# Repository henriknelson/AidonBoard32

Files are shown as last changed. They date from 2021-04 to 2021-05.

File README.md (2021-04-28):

# AidonBoard32
KiCad hardware project to facilitate the reading and forwarding of meter value data pushed through the P1-interface on electricity meters produced by Aidon together with a Espressifs ESP32-WROOM module on a single PCB.

3D View:
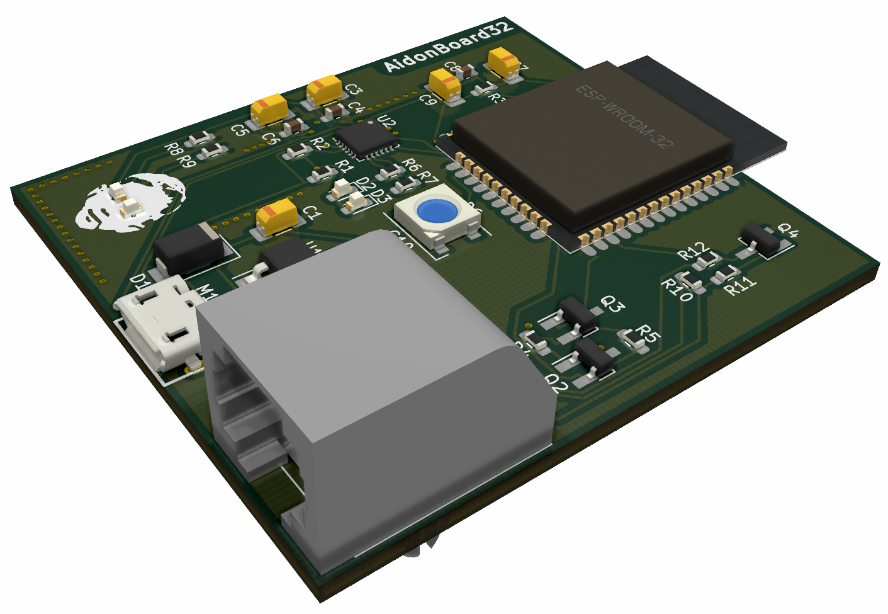
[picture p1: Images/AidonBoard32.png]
AidonBoard32 PCB 3D View


Schematic:
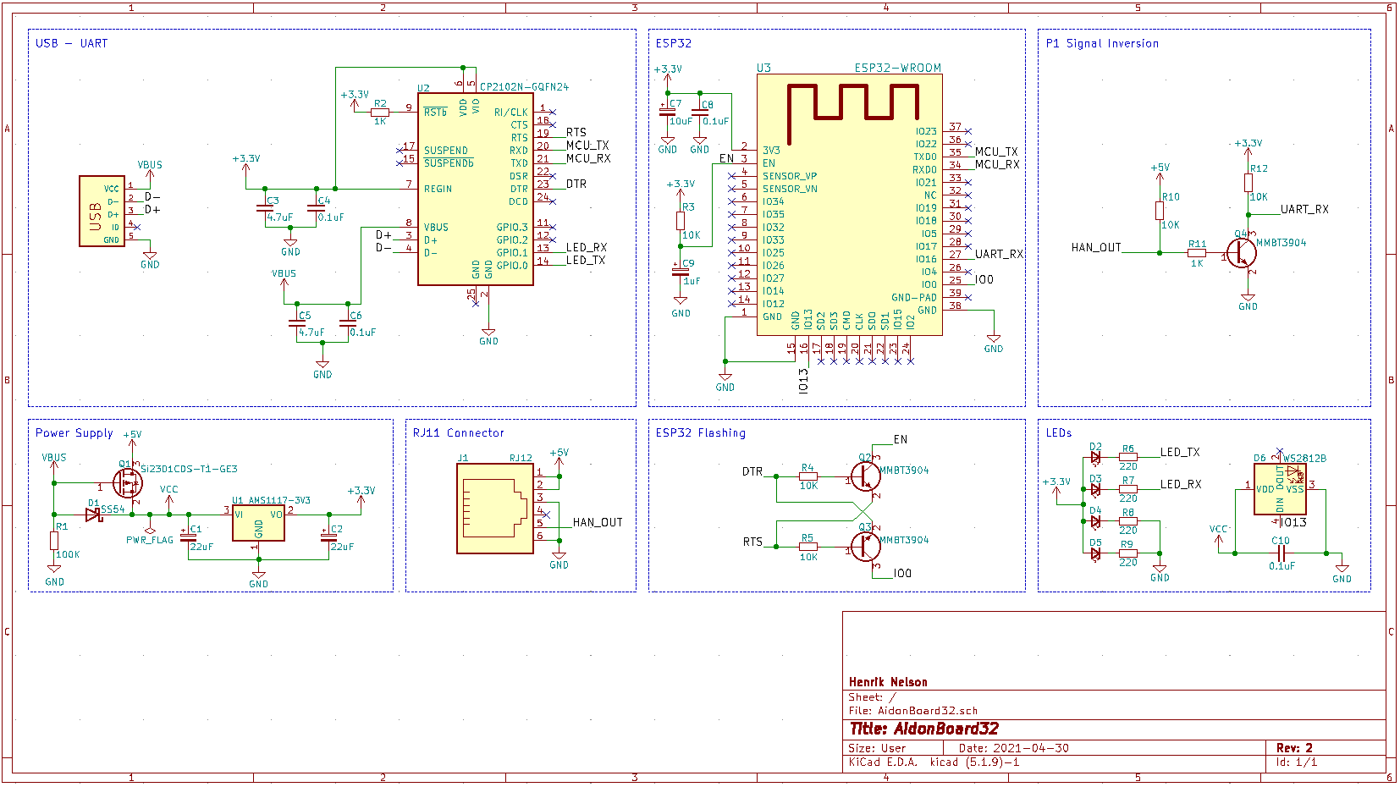
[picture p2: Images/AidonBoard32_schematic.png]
AidonBoard32 Schematic


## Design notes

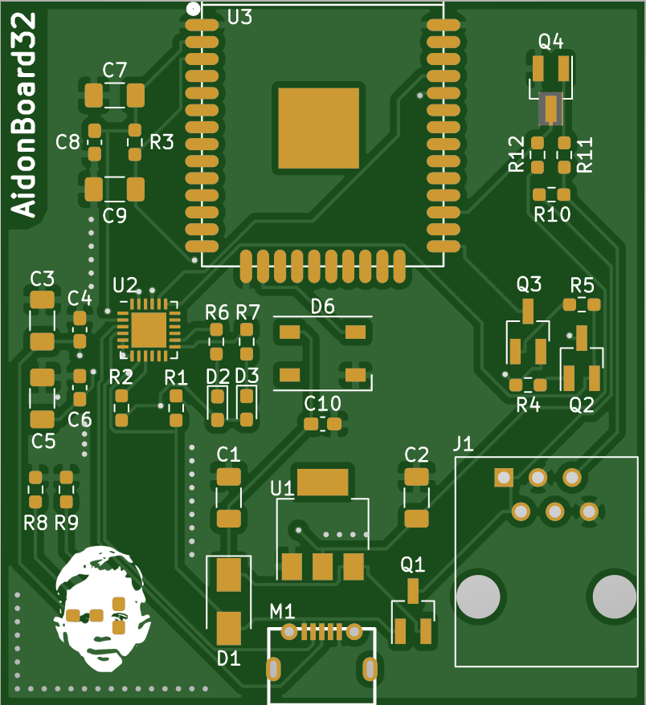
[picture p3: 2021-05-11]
Images/AidonBoard32_PCB_Front.png

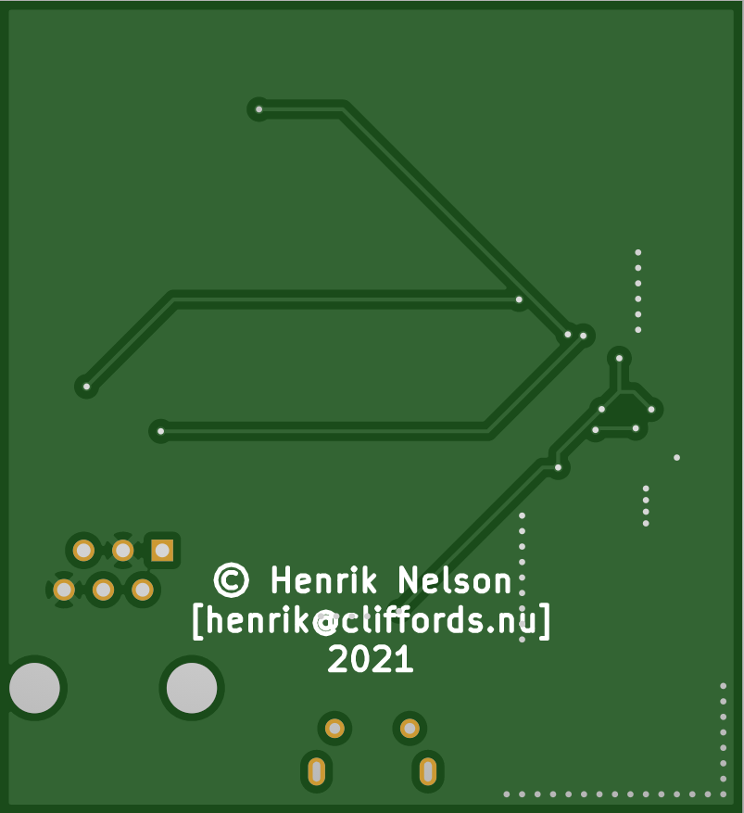
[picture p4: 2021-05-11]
Images/AidonBoard32_PCB_Back.png

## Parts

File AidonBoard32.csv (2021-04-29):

Comment | Designator | Footprint | LCSC
1uF | C10 | Capacitor_SMD:C_1206_3216Metric_Pad1.33x1.80mm_HandSolder | C123716
22uF | C1,C2 | Capacitor_SMD:C_1206_3216Metric_Pad1.33x1.80mm_HandSolder | C123296
4.7uF | C3,C5 | Capacitor_SMD:C_1206_3216Metric_Pad1.33x1.80mm_HandSolder | C129235
0.1uF | C4,C6,C7,C9 | Capacitor_SMD:C_1206_3216Metric_Pad1.33x1.80mm_HandSolder | C24497
10uF | C8 | Capacitor_SMD:C_1206_3216Metric_Pad1.33x1.80mm_HandSolder | C7177
LED_Small | D2,D3,D4 | LED_SMD:LED_1206_3216Metric_Pad1.42x1.75mm_HandSolder | C268283
WS2812B | D5 | LED_SMD:LED_WS2812B_PLCC4_5.0x5.0mm_P3.2mm | C114586
1N5819 | D1,D6 | Diode_SMD:D_SOD-123F | C82544
RJ12 | J1 | Henrik-Connectors:RJ11-6 | C77854
MICRO_USB_18_TH | M1 | Henrik-Connectors:MICRO_USB_18_TH | C91146
S8050 | Q1,Q2 | Package_TO_SOT_SMD:SOT-23_Handsoldering | C181158
1k | R1,R2,R3,R4 | Resistor_SMD:R_1206_3216Metric_Pad1.30x1.75mm_HandSolder | C131398
12k | R5,R6 | Resistor_SMD:R_1206_3216Metric_Pad1.30x1.75mm_HandSolder | C140050
10k | R7 | Resistor_SMD:R_1206_3216Metric_Pad1.30x1.75mm_HandSolder | C17902
AMS1117-3V3 | U1 | Package_TO_SOT_SMD:SOT-223 | C6186
CP2102N-GQFN24 | U2 | Package_DFN_QFN:QFN-24-1EP_4x4mm_P0.5mm_EP2.6x2.6mm | C1550551
ESP32-WROOM | U3 | Henrik-ESP32:ESP32-WROOM | C82899
74HC04D | U4 | Package_SO:SOIC-14_3.9x8.7mm_P1.27mm | C86613

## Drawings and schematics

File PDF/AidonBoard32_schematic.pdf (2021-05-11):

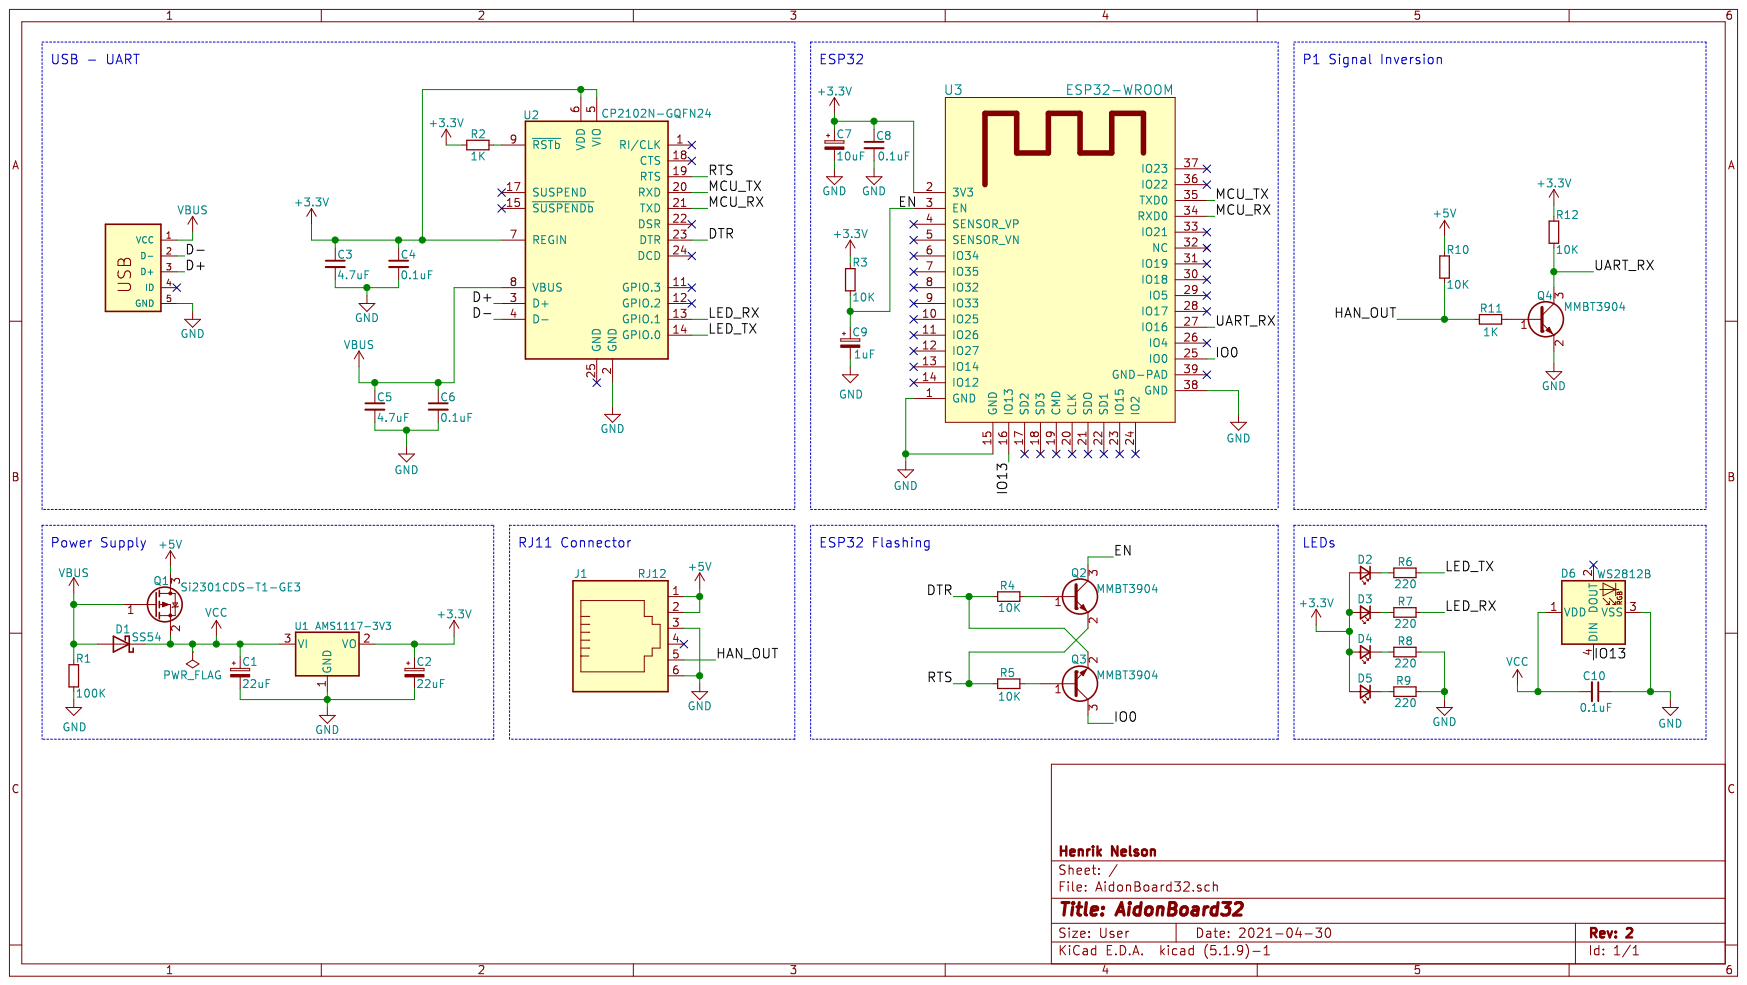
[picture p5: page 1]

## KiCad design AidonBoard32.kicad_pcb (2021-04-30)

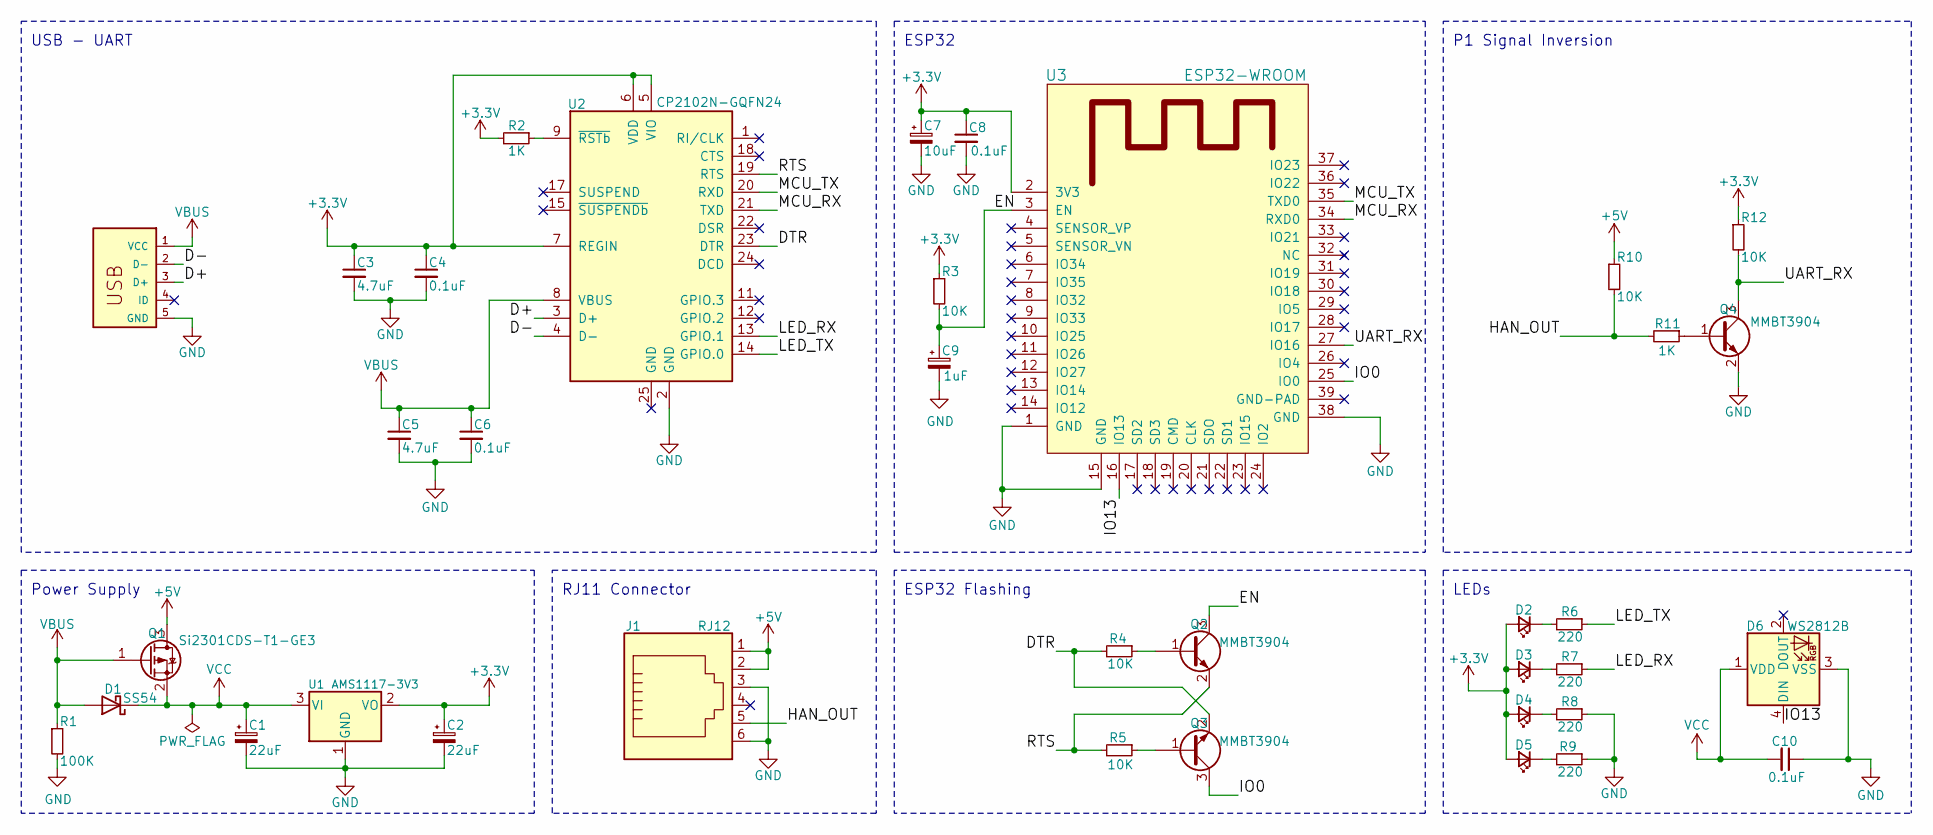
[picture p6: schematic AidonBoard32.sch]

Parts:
C1, C2: 22uF; C_1206_3216Metric_Pad1.33x1.80mm_HandSolder; LCSC C231297
C3, C5: 4.7uF; C_1206_3216Metric_Pad1.33x1.80mm_HandSolder; LCSC C129235
C4, C6, C8, C10: 0.1uF; C_0603_1608Metric_Pad1.08x0.95mm_HandSolder; LCSC C478888
C7: 10uF; C_1206_3216Metric_Pad1.33x1.80mm_HandSolder; LCSC C119052
C9: 1uF; C_1206_3216Metric_Pad1.33x1.80mm_HandSolder; LCSC C123716
D1: SS54; D_SMA; LCSC C22452
D2: LED_Small; LED_0603_1608Metric_Pad1.05x0.95mm_HandSolder; LCSC C273617
D3: LED_Small; LED_0603_1608Metric_Pad1.05x0.95mm_HandSolder; LCSC C192668
D4, D5: LED_Small; LED_0603_1608Metric_Pad1.05x0.95mm_HandSolder; LCSC C192315
D6: WS2812B; LED_WS2812B_PLCC4_5.0x5.0mm_P3.2mm; LCSC C114586
J1: RJ12; TE_5555165-1; LCSC C305981
M1: U-F-M5DD-Y-L; MICRO_USB_18_TH; LCSC C91146
Q1: Si2301CDS-T1-GE3; SOT-23_Handsoldering; LCSC C10487
Q2, Q3, Q4: MMBT3904; SOT-23_Handsoldering; LCSC C20526
R1: 100K; R_0603_1608Metric_Pad0.98x0.95mm_HandSolder; LCSC C491213
R2, R11: 1K; R_0603_1608Metric_Pad0.98x0.95mm_HandSolder; LCSC C491209
R3, R4, R5, R10, R12: 10K; R_0603_1608Metric_Pad0.98x0.95mm_HandSolder; LCSC C510087
R6, R7, R8, R9: 220; R_0603_1608Metric_Pad0.98x0.95mm_HandSolder; LCSC C441917
U1: AMS1117-3V3; SOT-223; LCSC C6186
U2: CP2102N-GQFN24; QFN-24-1EP_4x4mm_P0.5mm_EP2.6x2.6mm; LCSC C1550551
U3: ESP32-WROOM; LCSC C82899

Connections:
+3V3: C2.1, C3.1, C4.1, C7.1, C8.1, D2.2 (A), D3.2 (A), D4.2 (A), D5.2 (A), R2.2, R3.1, R12.1, U1.2 (VO), U2.5 (VIO), U2.6 (VDD), U2.7 (REGIN), U3.2 (3V3)
+5V: J1.1, J1.2, Q1.3 (D), R10.1
/D+: M1.3 (D+), U2.3 (D+)
/D-: M1.2 (D-), U2.4 (D-)
/DTR: Q3.2 (E), R4.2, U2.23 (DTR)
/EN: C9.1, Q2.3 (C), R3.2, U3.3 (EN)
/HAN_OUT: J1.5, R10.2, R11.2
/IO0: Q3.3 (C), U3.25 (IO0)
/IO13: D6.4 (DIN), U3.16 (IO13)
/LED_RX: R7.1, U2.13 (GPIO.1)
/LED_TX: R6.1, U2.14 (GPIO.0)
/MCU_RX: U2.21 (TXD), U3.34 (RXD0)
/MCU_TX: U2.20 (RXD), U3.35 (TXD0)
/RTS: Q2.2 (E), R5.2, U2.19 (RTS)
/UART_RX: Q4.3 (C), R12.2, U3.27 (IO16)
GND: C1.2, C2.2, C3.2, C4.2, C5.2, C6.2, C7.2, C8.2, C9.2, C10.1, D6.3 (VSS), J1.3, J1.6, M1.5 (GND), Q4.2 (E), R1.2, R8.1, R9.1, U1.1 (GND), U2.2 (GND), U3.1 (GND), U3.15 (GND), U3.38 (GND)
unnamed: D2.1 (K), R6.2
unnamed: D3.1 (K), R7.2
unnamed: D4.1 (K), R8.2
unnamed: D5.1 (K), R9.2
unnamed: Q2.1 (B), R4.1
unnamed: Q3.1 (B), R5.1
unnamed: Q4.1 (B), R11.1
unnamed: R2.1, U2.9 (~RSTb)
VBUS: C5.1, C6.1, D1.2 (A), M1.1 (VCC), Q1.1 (G), R1.1, U2.8 (VBUS)
VCC: C1.1, C10.2, D1.1 (K), D6.1 (VDD), Q1.2 (S), U1.3 (VI)

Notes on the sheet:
USB - UART
Power Supply
LEDs
ESP32
P1 Signal Inversion
ESP32 Flashing
RJ11 Connector

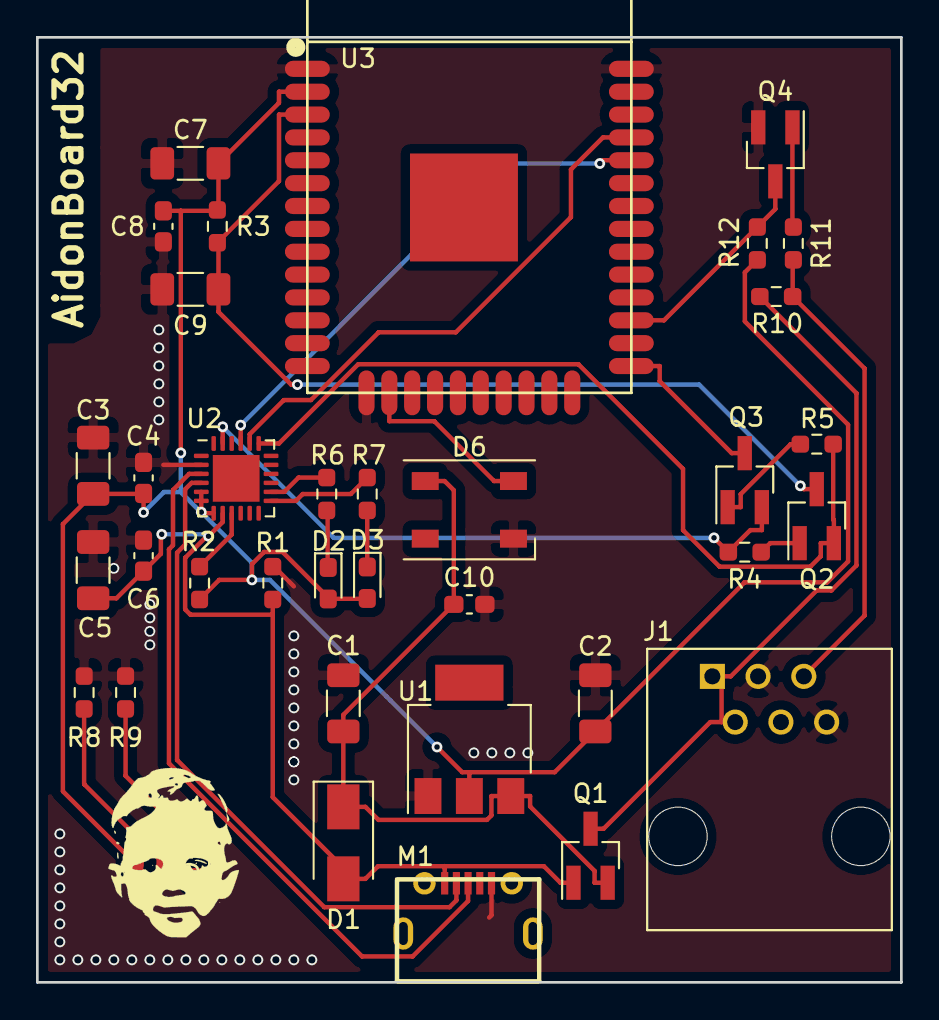
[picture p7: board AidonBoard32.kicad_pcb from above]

Board: 2 copper layers, 48.0 x 52.5 mm, 38 parts (0 on the bottom side), 26 nets.

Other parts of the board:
G1: LOGO; Harry_3

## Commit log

2021-04-28 Finished first revision of AidonBoard32!
    [AidonBoard32-B_Cu.gbr, AidonBoard32-B_Mask.gbr, AidonBoard32-B_SilkS.gbr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]
2021-04-29 Fixed routing
    [AidonBoard32.dsn, AidonBoard32.kicad_pcb, AidonBoard32.sch]
2021-04-29 Fixed small issues
    [AidonBoard32.dsn, AidonBoard32.kicad_pcb, AidonBoard32.sch]
2021-04-30 New gerber files
    [AidonBoard32-B_Cu.gbr, AidonBoard32-B_Mask.gbr, AidonBoard32-B_SilkS.gbr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]
2021-05-11 Updated project with the latest schematic/gerber files/3d renders
2021-05-13 Updated some component values in schematic
    [AidonBoard32.sch]

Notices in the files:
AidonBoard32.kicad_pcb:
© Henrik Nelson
